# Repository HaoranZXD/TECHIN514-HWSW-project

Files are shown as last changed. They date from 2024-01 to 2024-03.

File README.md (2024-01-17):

# "AtmosTrack" Personal Weather Station

## Overview

"AtmosTrack" provides localized weather monitoring by collecting atmospheric data in real-time. It's designed for domestic use, featuring an outdoor sensor unit that is compact and waterproof. The indoor display boasts an intuitive gauge and vibrant LED indicators, all encapsulated within a modern design.

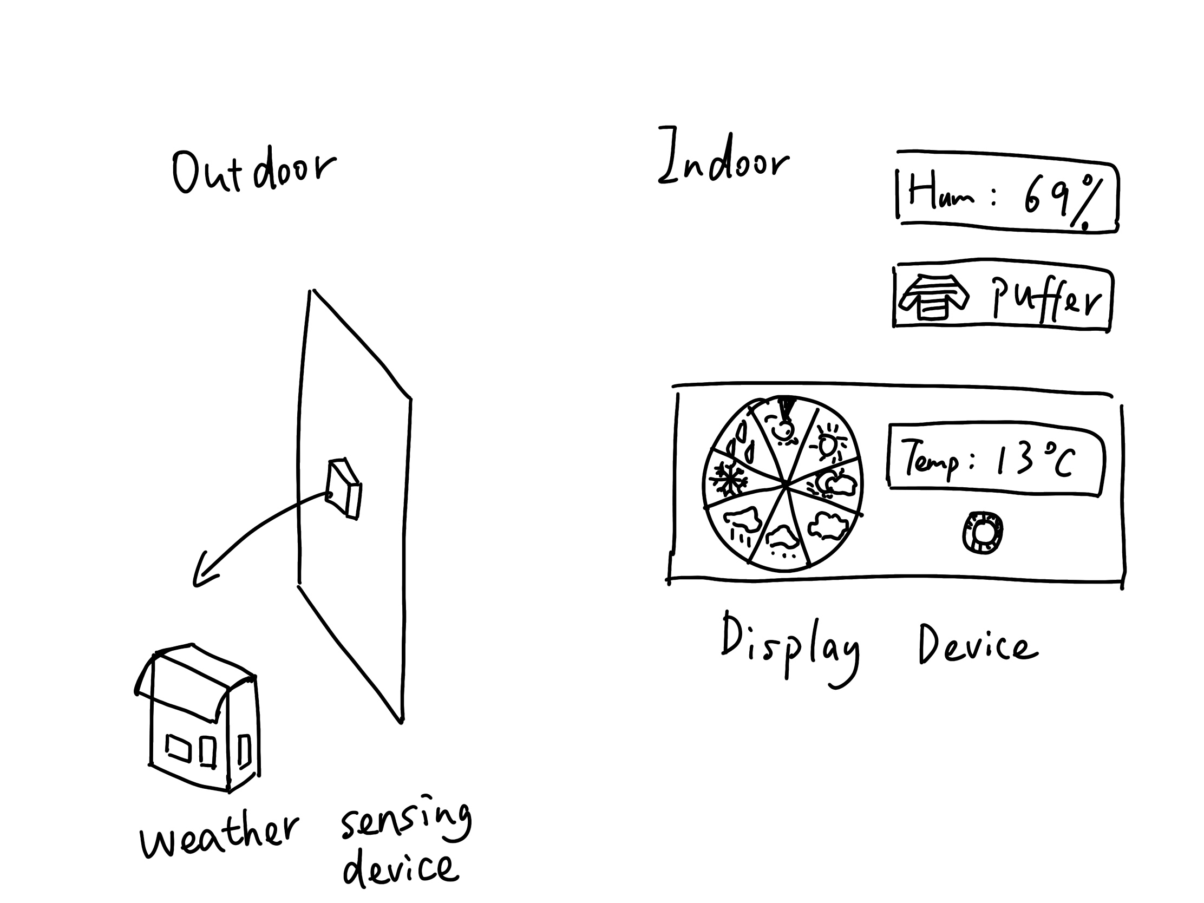
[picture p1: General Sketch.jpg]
General Sketch


## Sensing Device - "AtmosSensor"

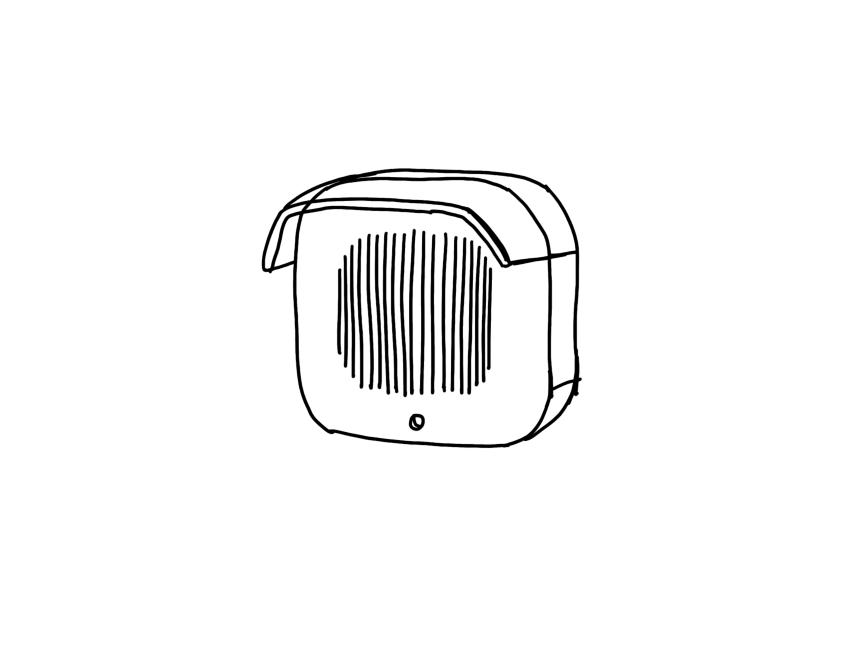
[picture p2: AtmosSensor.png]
Detailed Sketch of Sensing Device


The "AtmosSensor" outdoor unit is outfitted with the HTU21D sensor for accurate humidity and temperature measurements, alongside the CCS811 sensor for CO2 and VOC levels. These are managed by the ESP32 processor. Data is wirelessly transmitted to the indoor unit via Wi-Fi. The unit is powered by a LP323450 rechargeable lithium polymer ion battery pack, ensuring continuous operation.

## Display Device - "AtmosDisplay"

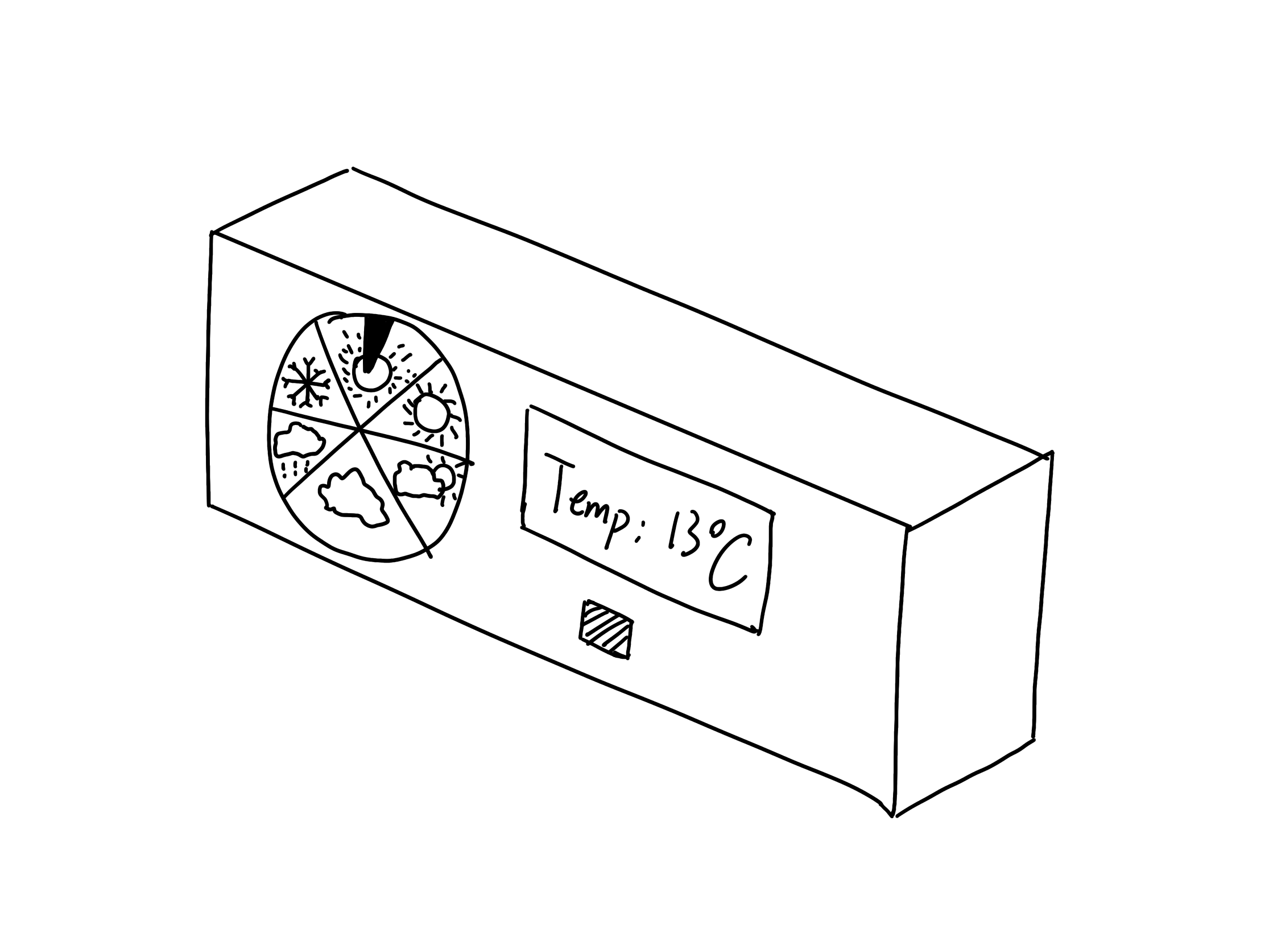
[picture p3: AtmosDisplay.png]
Detailed Sketch of Display Device


The indoor "AtmosDisplay" presents the weather data on a ST7735R TFT LCD and utilizes a custom gauge with a stepper motor (28BYJ-48) for an analog display. It's powered by an ESP32 processor, featuring Wi-Fi connectivity for real-time data updates. User interaction is facilitated through a capacitive touch button (TTP223). The display unit is powered by a 18650 lithium-ion battery, providing portability and easy recharging.

## Communication and System Diagrams

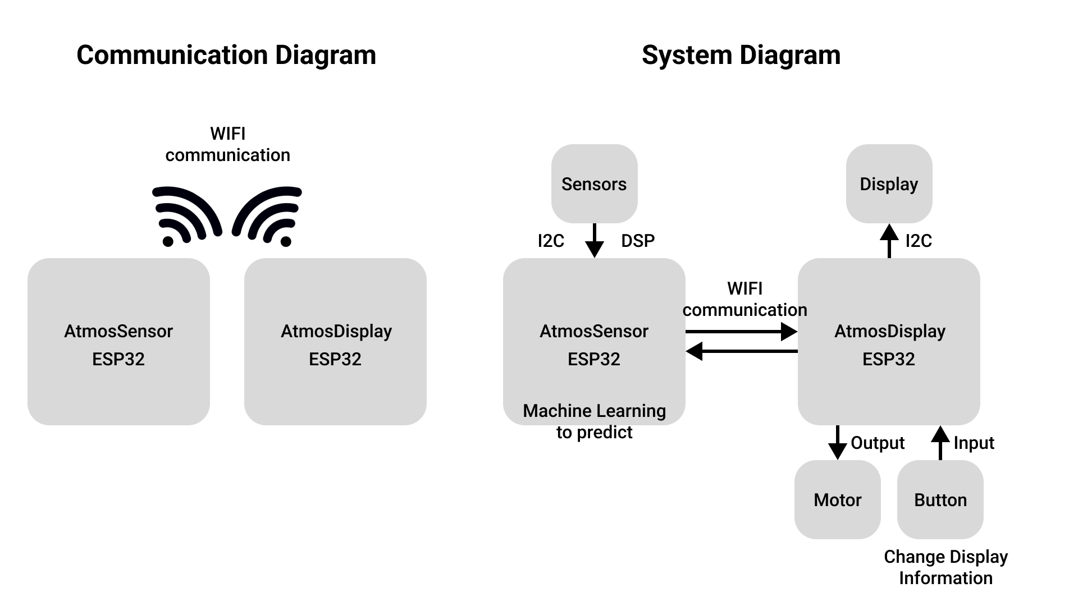
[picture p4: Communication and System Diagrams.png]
Communication and System Diagrams


The "AtmosSensor" and "AtmosDisplay" units communicate wirelessly through Wi-Fi, ensuring a consistent stream of data. The ESP32 of "AtmosSensor" is responsible for gathering sensor data and performing initial processing before transmission. The ESP32 of "AtmosDisplay" processes the data upon receipt and updates the display accordingly, offering a dynamic and interactive way to visualize weather data.

## Datasheets Folder

- `[HTU21D](datasheets/HTU21D.pdf)`
- `[CCS811](datasheets/CCS811.pdf)`
- `[ESP32](datasheets/ESP32-S3.pdf)`
- `[28BYJ-48](datasheets/28BYJ-48.pdf)`
- `[ST7735R](datasheets/ST7735R.pdf)`
- `[TTP223](datasheets/TTP223.pdf)`
- `[ICR18650](datasheets/ICR18650.pdf)`
- `[LP323450](datasheets/LP323450.pdf)`

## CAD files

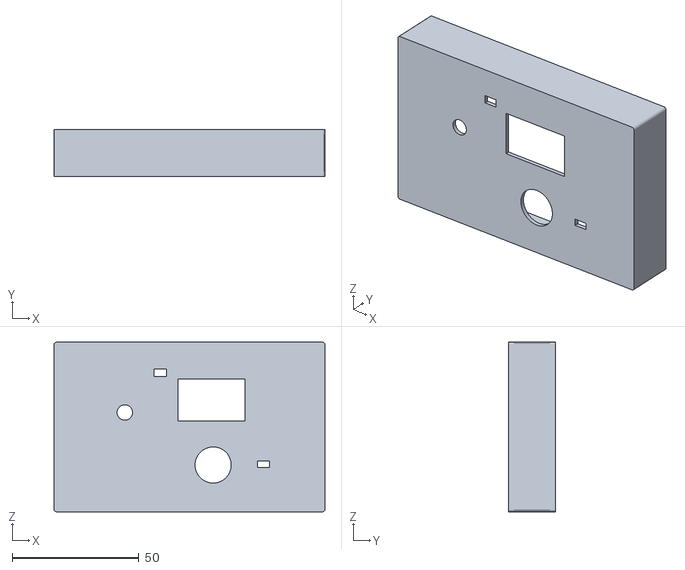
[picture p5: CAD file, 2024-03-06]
3Dmodel/DisplayA.stl
107.0 x 18.5 x 67.0

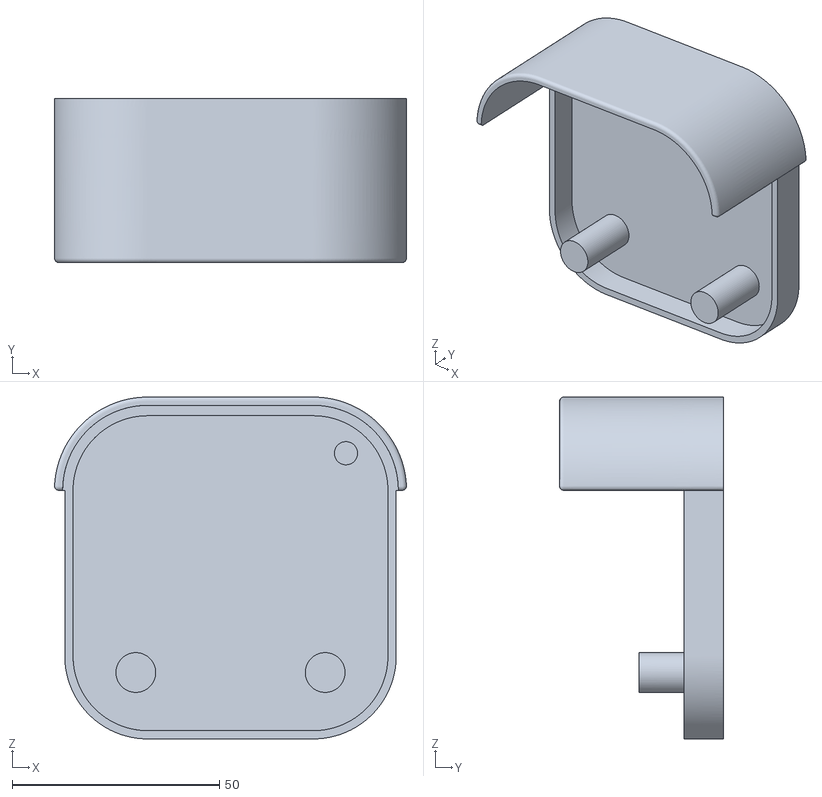
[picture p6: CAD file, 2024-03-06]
3Dmodel/sensorB.stl
85.0 x 39.6 x 82.5

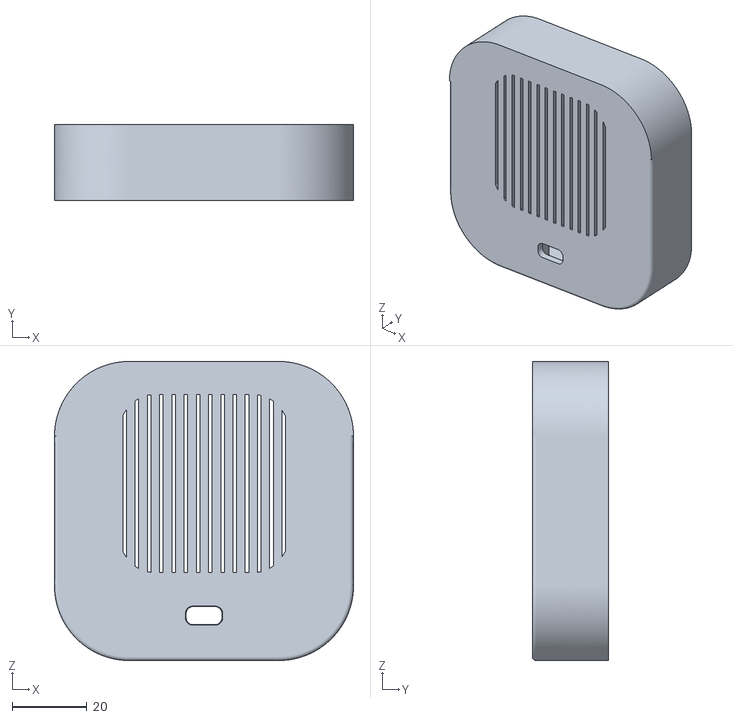
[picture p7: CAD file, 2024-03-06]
3Dmodel/sensorA.stl
80.0 x 20.4 x 80.0

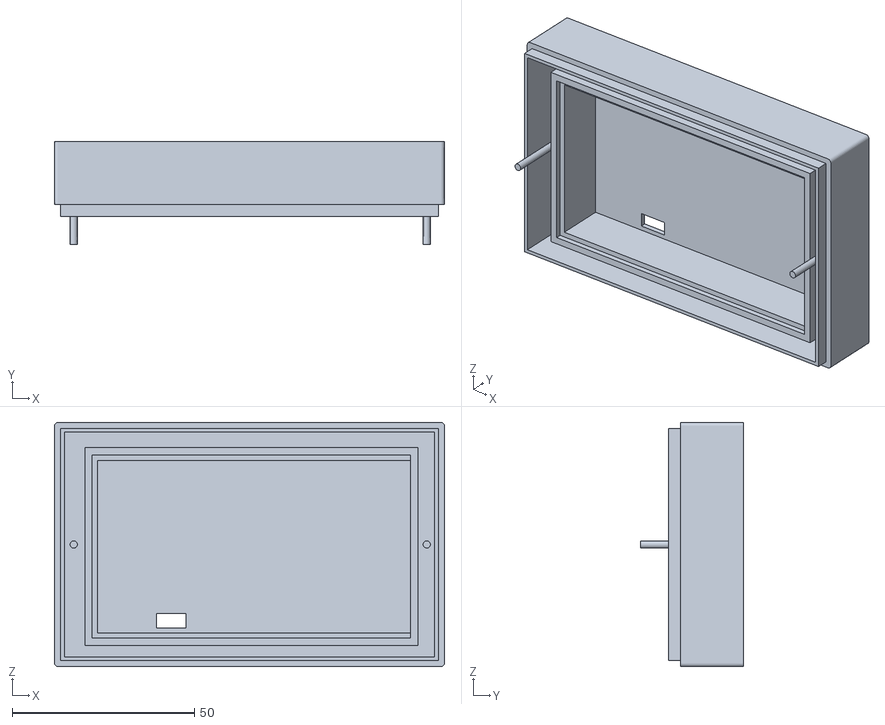
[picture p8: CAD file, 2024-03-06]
3Dmodel/DisplayB.stl
107.0 x 28.2 x 67.0

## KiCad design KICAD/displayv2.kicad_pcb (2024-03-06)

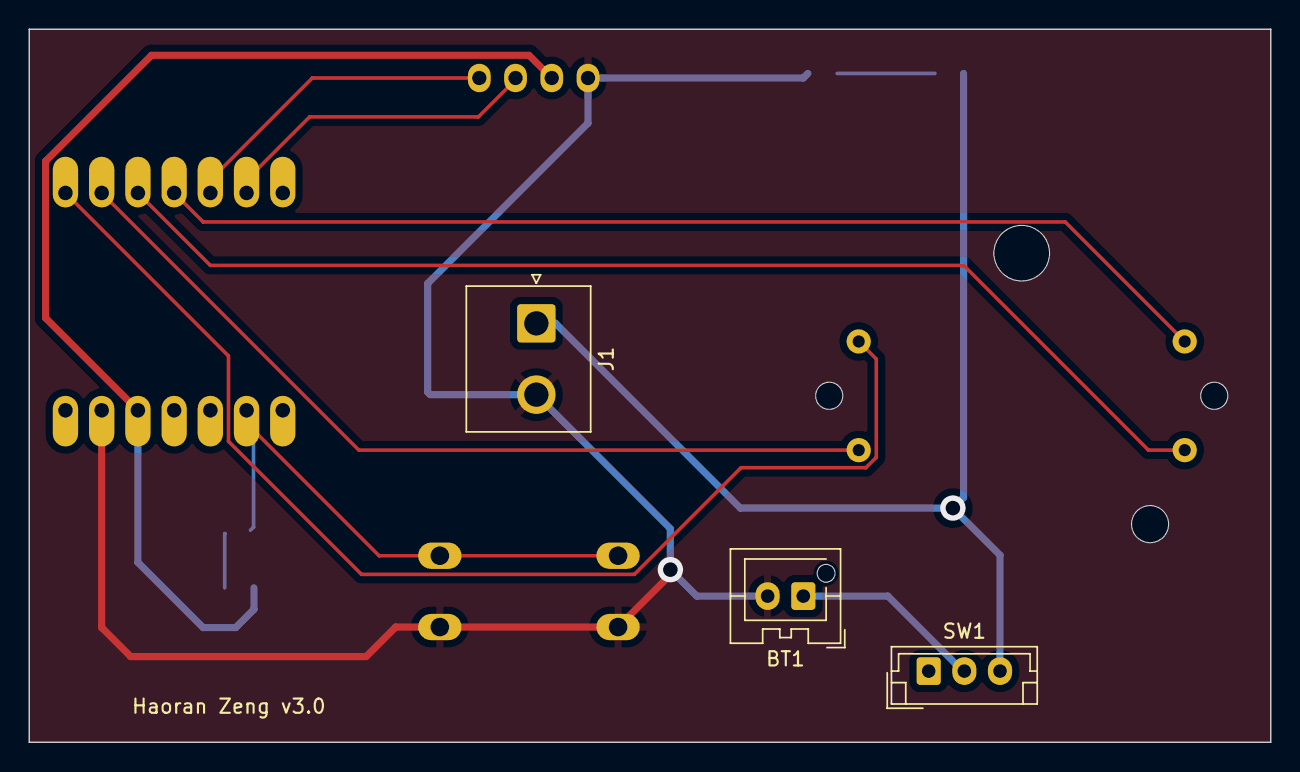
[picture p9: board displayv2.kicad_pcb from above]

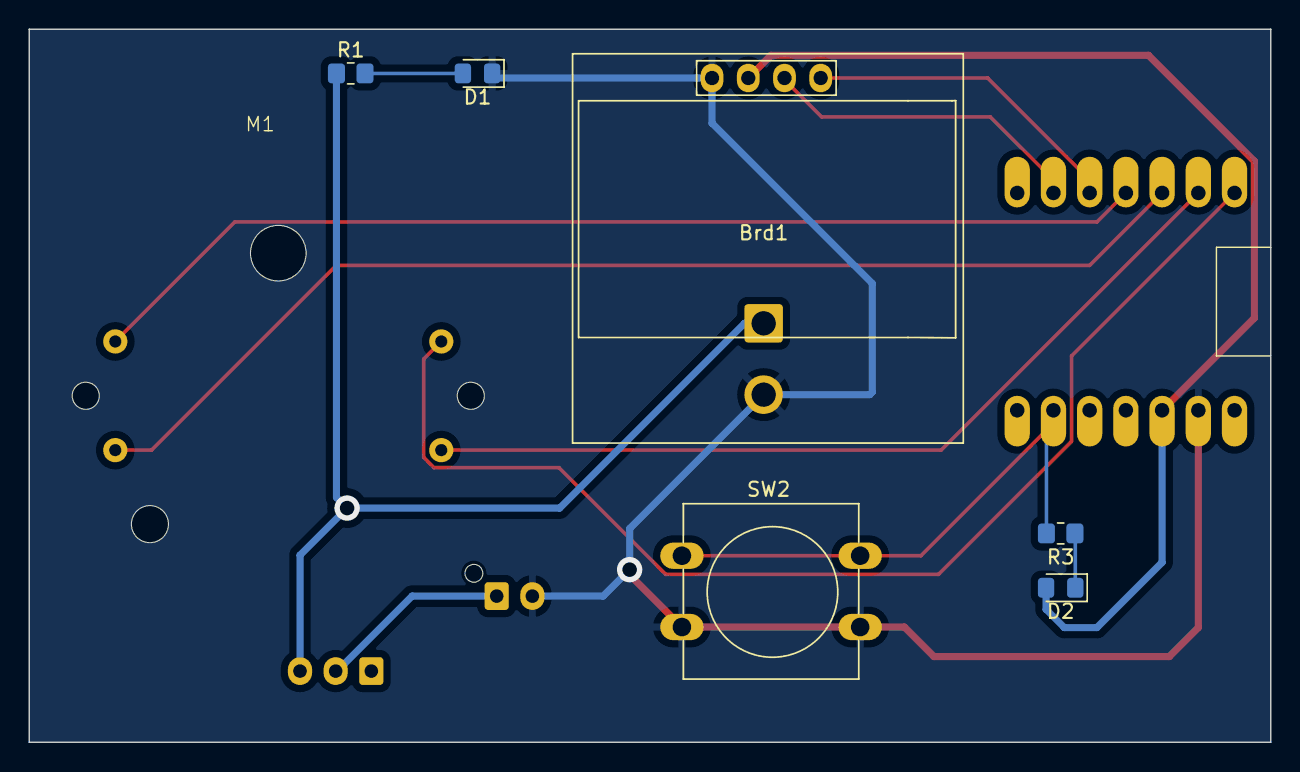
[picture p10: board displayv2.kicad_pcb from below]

Board: 2 copper layers, 87.1 x 50.0 mm, 11 parts (8 on the bottom side), 13 nets.

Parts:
BT1: Battery_Cell; JST_XA_B02B-XASK-1-A_1x02_P2.50mm_Vertical
Brd1: SSD1306; 128x64OLED
D1, D2: LED; LED_0805_2012Metric_Pad1.15x1.40mm_HandSolder
J1: Conn_01x02_Pin; JST_NV_B02P-NV_1x02_P5.00mm_Vertical
M1: Stepper_Motor_bipolar; x27_stepper
R1: 85Ω; R_0805_2012Metric_Pad1.20x1.40mm_HandSolder
R3: 65Ω; R_0805_2012Metric_Pad1.20x1.40mm_HandSolder
SW1: SW_SPDT; JST_EH_B3B-EH-A_1x03_P2.50mm_Vertical
SW2: SW_SPST; SW_PUSH-12mm
U1: XIAO_ESP32_SENSE

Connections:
/3V3: Brd1.2 (VCC), D2.2 (A), U1.10 (3V3)
/BAT: BT1.1 (+), SW1.2 (B)
/BTN: R3.2, SW2.1 (A), U1.13 (GPIO7_A8_D8_SCK)
/MOTOR1: M1.1, U1.1 (GPIO1_A0_D0)
/MOTOR2: M1.2 (-), U1.2 (GPIO2_A1_D1)
/MOTOR3: M1.3, U1.3 (GPIO3_A2_D2)
/MOTOR4: M1.4, U1.4 (GPIO4_A3_D3)
/SCL: Brd1.3 (SCL), U1.6 (GPIO6_A5_D5_SCL)
/SDA: Brd1.4 (SDA), U1.5 (GPIO4_A3_D3_SDA)
/VCC: J1.1, R1.1, SW1.3 (C)
GND: BT1.2 (-), Brd1.1 (GND), D1.1 (K), J1.2, SW2.2 (B), U1.9 (GND)
unnamed: D1.2 (A), R1.2
unnamed: D2.1 (K), R3.1

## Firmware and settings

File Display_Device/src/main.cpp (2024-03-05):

#include <Arduino.h>
#include <BLEDevice.h>
#include <BLEUtils.h>
#include <BLEScan.h>
#include <BLEAdvertisedDevice.h>
#include <Adafruit_GFX.h>
#include <Adafruit_SSD1306.h>
#include <SwitecX25.h>

// Display settings
#define SCREEN_WIDTH 128 // OLED display width, in pixels
#define SCREEN_HEIGHT 64 // OLED display height, in pixels
#define OLED_RESET     -1 // Reset pin # (or -1 if sharing Arduino reset pin)
Adafruit_SSD1306 display(SCREEN_WIDTH, SCREEN_HEIGHT, &Wire, OLED_RESET);

// standard X25.168 ranges from 0 to 315 degrees, at 1/3 degree increments
#define STEPS 945

// For motors connected to D0, D1, D2, D3
SwitecX25 motor1(STEPS, D0, D1, D2, D3);

// BLE settings
static BLEUUID serviceUUID("d4d8b28b-8928-4044-b3b2-fbed8f587fd0");
static BLEUUID charUUID("c8e44563-c8f3-4822-8a41-9f4df10fa9ac");

static boolean doConnect = false;
static boolean connected = false;
static boolean doScan = false;
static BLERemoteCharacteristic* pRemoteCharacteristic;
static BLEAdvertisedDevice* myDevice;

String receivedData = "";

void displayMessage(String message) {
  display.clearDisplay();
  display.setTextSize(1); // Normal 1:1 pixel scale
  display.setTextColor(SSD1306_WHITE); // Draw white text
  display.setCursor(0,0); // Start at top-left corner
  display.println(message);
  display.display();
}

void processData(String data) {
  Serial.println("Processed Data: " + data);
  // displayMessage("Data: " + data);
}

static void notifyCallback(
  BLERemoteCharacteristic* pBLERemoteCharacteristic,
  uint8_t* pData,
  size_t length,
  bool isNotify) {
    receivedData = String((char*)pData, length);
    Serial.println("Received Data: " + receivedData);
    processData(receivedData);
}

class MyClientCallback : public BLEClientCallbacks {
  void onConnect(BLEClient* pclient) {
    connected = true;
    displayMessage("Connected");
  }

  void onDisconnect(BLEClient* pclient) {
    connected = false;
    displayMessage("Disconnected");
  }
};

bool connectToServer() {
    Serial.print("Connecting to ");
    Serial.println(myDevice->getAddress().toString().c_str());

    BLEClient*  pClient  = BLEDevice::createClient();
    Serial.println(" - Created client");

    pClient->setClientCallbacks(new MyClientCallback());

    pClient->connect(myDevice);
    Serial.println(" - Connected to server");

    pClient->setMTU(517);

    BLERemoteService* pRemoteService = pClient->getService(serviceUUID);
    if (pRemoteService == nullptr) {
      Serial.print("Failed to find our service UUID: ");
      Serial.println(serviceUUID.toString().c_str());
      pClient->disconnect();
      return false;
    }
    Serial.println(" - Found our service");

    pRemoteCharacteristic = pRemoteService->getCharacteristic(charUUID);
    if (pRemoteCharacteristic == nullptr) {
      Serial.print("Failed to find our characteristic UUID: ");
      Serial.println(charUUID.toString().c_str());
      pClient->disconnect();
      return false;
    }
    Serial.println(" - Found our characteristic");

    if(pRemoteCharacteristic->canNotify())
      pRemoteCharacteristic->registerForNotify(notifyCallback);

    return true;
}

class MyAdvertisedDeviceCallbacks: public BLEAdvertisedDeviceCallbacks {
  void onResult(BLEAdvertisedDevice advertisedDevice) {
    Serial.print("Found BLE Device: ");
    Serial.println(advertisedDevice.toString().c_str());

    if (advertisedDevice.haveServiceUUID() && advertisedDevice.isAdvertisingService(serviceUUID)) {
      BLEDevice::getScan()->stop();
      myDevice = new BLEAdvertisedDevice(advertisedDevice);
      doConnect = true;
      doScan = false;
    }
  }
};

void setup() {
  Serial.begin(115200);
  Serial.println("Starting Arduino BLE Client application...");
  BLEDevice::init("");

  if(!display.begin(SSD1306_SWITCHCAPVCC, 0x3C)) { 
    Serial.println(F("SSD1306 allocation failed"));
    for(;;);
  }
  display.display();
  delay(2000);
  display.clearDisplay();
    // Initialize the stepper motor and move it to zero position
  motor1.zero(); // Make sure your motor library supports this or use motor.setPosition(0) if not
  while (motor1.currentStep != motor1.targetStep) {
    motor1.update();
  }

  // Now move the stepper motor to its maximum position
  motor1.setPosition(STEPS); // Set to the maximum steps the motor can take
  while (motor1.currentStep != motor1.targetStep) {
    motor1.update();
  }

  // Optionally, return the motor to its mid-point or starting position for your application
  motor1.setPosition(STEPS / 2);
  while (motor1.currentStep != motor1.targetStep) {
    motor1.update();
  }


  BLEScan* pBLEScan = BLEDevice::getScan();
  pBLEScan->setAdvertisedDeviceCallbacks(new MyAdvertisedDeviceCallbacks());
  pBLEScan->setInterval(1349);
  pBLEScan->setWindow(449);
  pBLEScan->setActiveScan(true);
  pBLEScan->start(5, false);
}

void processReceivedData(String data) {
  // Initial indices for parsing the data
  int tempStart = data.indexOf("Temp: ") + 6;
  int humStart = data.indexOf("Hum: ", tempStart) + 5;
  int pressStart = data.indexOf("Press: ", humStart) + 7;
  int luxStart = data.indexOf("Lux: ", pressStart) + 5;

  // Find end indices for each segment based on known separators
  int tempEnd = data.indexOf(" C", tempStart);
  int humEnd = data.indexOf(" %", humStart);
  int pressEnd = data.indexOf(" hPa", pressStart);
  int luxEnd = data.length(); // Assumes lux is the last value in the string

  // Parse each segment to its corresponding float
  float temperature = data.substring(tempStart, tempEnd).toFloat();
  float humidity = data.substring(humStart, humEnd).toFloat();
  float pressure = data.substring(pressStart, pressEnd).toFloat();
  float lux = data.substring(luxStart, luxEnd).toFloat();

  int targetStep = (int)(temperature * (STEPS / 40.0));
  motor1.setPosition(targetStep);

  while (motor1.currentStep != motor1.targetStep) {
    motor1.update();
  }

  // Display parsed values on the OLED
  display.clearDisplay();
  display.setCursor(0,0);
  display.print("Temp: ");
  display.print(temperature, 1);
  display.print(" C");
  display.setCursor(0, 15);
  display.print("Hum: ");
  display.print(humidity, 1);
  display.print(" %");
  display.setCursor(0, 30);
  display.print("Pres: ");
  display.print(pressure, 2);
  display.print(" hPa");
  display.setCursor(0, 45); // Adjust as necessary for your display's resolution
  display.print("Lux: ");
  display.print(lux);
  display.display();
}


void loop() {
  if (doConnect) {
    if (connectToServer()) {
      Serial.println("We are now connected to the BLE Server.");
      displayMessage("Connected to Server");
    } else {
      Serial.println("Failed to connect to the server; there is nothing more we will do.");
      displayMessage("Failed to Connect");
    }
    doConnect = false;
  }

  if (connected) {
    // This part of the loop runs when the client is connected to the BLE server.
    // Display any other status or operation specific messages if required.
  } else if (doScan) {
    displayMessage("Scanning...");
    BLEDevice::getScan()->start(0); // 0 means continuous scanning
  }

  // Optionally, check for received data and display it.
  if (!receivedData.isEmpty()) {
    processReceivedData(receivedData);
    receivedData = ""; // Clear after displaying to avoid repetitive display
  }

  delay(1000); // Delay a second between loops to manage the workflow and not overload the BLE communication.
}

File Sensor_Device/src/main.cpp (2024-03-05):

#include <Arduino.h>
#include <Arduino.h>
#include <BLEDevice.h>
#include <BLEServer.h>
#include <BLEUtils.h>
#include <BLE2902.h>
#include <Wire.h>
#include <Adafruit_Sensor.h>
#include <Adafruit_BME280.h>
#include <Adafruit_VEML7700.h>

// BLE settings
BLEServer* pServer = NULL;
BLECharacteristic* pCharacteristic = NULL;
bool deviceConnected = false;
bool oldDeviceConnected = false;
unsigned long previousMillis = 0;
const long interval = 1000;

// UUIDs for BLE service and characteristic
#define SERVICE_UUID        "d4d8b28b-8928-4044-b3b2-fbed8f587fd0"
#define CHARACTERISTIC_UUID "c8e44563-c8f3-4822-8a41-9f4df10fa9ac"

// Sensor setup
Adafruit_VEML7700 veml = Adafruit_VEML7700();
Adafruit_BME280 bme;

// Filtered values initialization
float alpha = 0.2;
float filteredTemperature = 0.0;
float filteredHumidity = 0.0;
float filteredPressure = 0.0;
float filteredLux = 0.0;

class MyServerCallbacks : public BLEServerCallbacks {
    void onConnect(BLEServer* pServer) {
        deviceConnected = true;
    };

    void onDisconnect(BLEServer* pServer) {
        deviceConnected = false;
    }
};

void setup() {
    Serial.begin(115200);
    Wire.begin();
    Serial.println("Starting BLE work and sensor initialization!");

    // Initialize BME280
    if (!bme.begin(0x76)) {  
        Serial.println("Could not find a valid BME280 sensor, check wiring!");
        while (1);
    }

    // Initialize VEML7700
    if (!veml.begin()) {
        Serial.println("No VEML7700 sensor found... check your wiring?");
        while (1);
    }

    // Configure VEML7700 settings
    veml.setGain(VEML7700_GAIN_1);
    veml.setIntegrationTime(VEML7700_IT_100MS);

    // BLE initialization
    BLEDevice::init("SensorServer");
    pServer = BLEDevice::createServer();
    pServer->setCallbacks(new MyServerCallbacks());
    BLEService *pService = pServer->createService(SERVICE_UUID);
    pCharacteristic = pService->createCharacteristic(
        CHARACTERISTIC_UUID,
        BLECharacteristic::PROPERTY_READ |
        BLECharacteristic::PROPERTY_WRITE |
        BLECharacteristic::PROPERTY_NOTIFY
    );
    pCharacteristic->addDescriptor(new BLE2902());
    pService->start();

    BLEAdvertising *pAdvertising = BLEDevice::getAdvertising();
    pAdvertising->addServiceUUID(SERVICE_UUID);
    pAdvertising->setScanResponse(true);
    pAdvertising->setMinPreferred(0x06);
    BLEDevice::startAdvertising();
    Serial.println("Characteristic defined! Sensors are ready!");
}

void loop() {
    // Read data from sensors
    float temperature = bme.readTemperature();
    float humidity = bme.readHumidity();
    float pressure = bme.readPressure() / 100.0F; // Convert Pa to hPa for readability
    float lux = veml.readLux();

    // Apply exponential decay filter to sensor readings
    filteredTemperature = alpha * temperature + (1 - alpha) * filteredTemperature;
    filteredHumidity = alpha * humidity + (1 - alpha) * filteredHumidity;
    filteredPressure = alpha * pressure + (1 - alpha) * filteredPressure;
    filteredLux = alpha * lux + (1 - alpha) * filteredLux;

    if (deviceConnected) {
        unsigned long currentMillis = millis();
        if (currentMillis - previousMillis >= interval) {
            // Prepare and send the BLE message
            char message[100];
            snprintf(message, sizeof(message), "Temp: %.1f C, Hum: %.1f %%, Press: %.1f hPa, Lux: %.1f", filteredTemperature, filteredHumidity, filteredPressure, filteredLux);
            pCharacteristic->setValue(message);
            pCharacteristic->notify();
            Serial.println(message);

            previousMillis = currentMillis;
        }
    }

    // Handle BLE connection status changes
    if (!deviceConnected && oldDeviceConnected) {
        delay(500); // Give the bluetooth stack the chance to get things ready
        pServer->startAdvertising(); // Advertise again
        Serial.println("Start advertising");
        oldDeviceConnected = deviceConnected;
    }

    if (deviceConnected && !oldDeviceConnected) {
        oldDeviceConnected = deviceConnected;
    }

    delay(1000);
    } //

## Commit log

2024-01-18 Add first version of sch and pcb
    [test.kicad_pcb, test.kicad_sch]
2024-02-06 Add a simple power mode spreadsheet
    [Simple_ Power Model for TECHIN514.xlsx]
2024-03-06 final version of kicad
    [displayv2.kicad_pcb]
